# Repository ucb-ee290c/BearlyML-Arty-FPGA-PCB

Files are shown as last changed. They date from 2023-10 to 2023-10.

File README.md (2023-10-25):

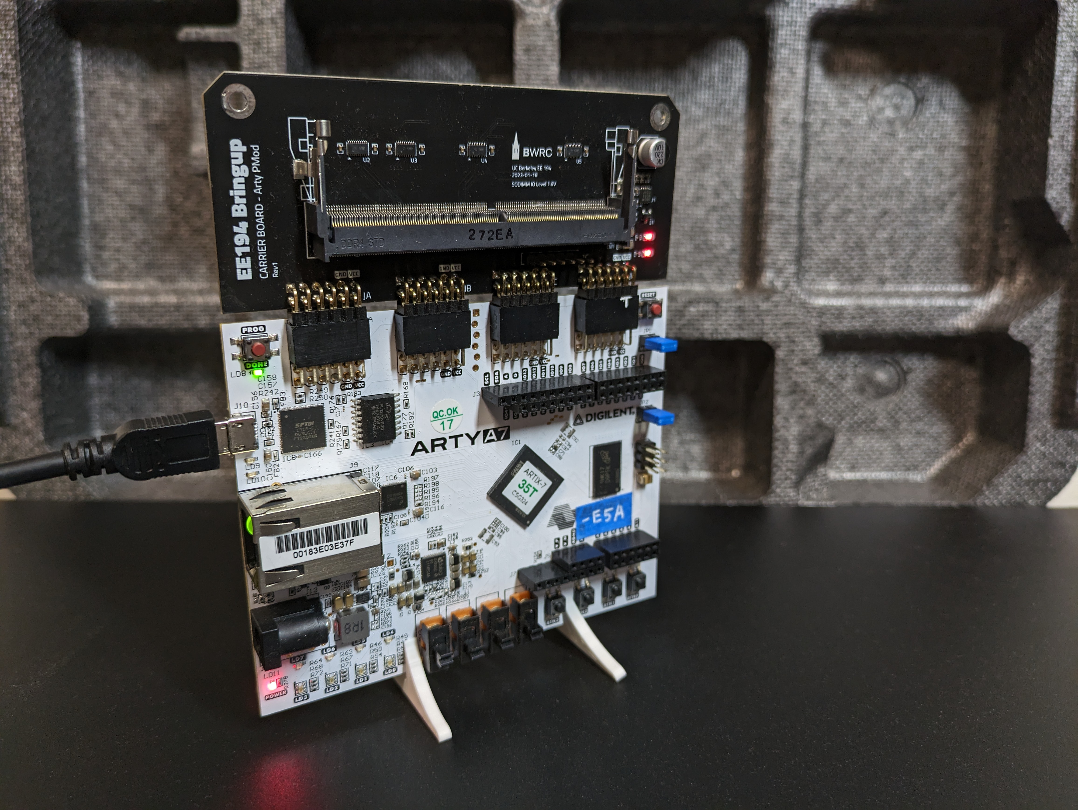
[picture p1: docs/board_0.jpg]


# BearlyML Carrier Arty PCB

This is an adapter board between BearlyML Module board and the Arty 35T / 100T FPGA.

## Functional Description

This board level-shifts between the BearlyML 1.8V signal and the Arty PMOD 3.3V signal using the [TXB0108DQSR](https://www.digikey.com/short/mvzwjjp7) level shifter. 

## Project Links

[BearlyML 2022 SoC Specification](https://docs.google.com/document/d/1Ldz2ZDB1uXTN-R59TmTNYh7_aXbSfiJJrKeP0uHo0qY/edit?usp=sharing)

[BearlyML 2022 Testing Note](https://docs.google.com/presentation/d/11BuBN2AjHtR5hc7lh9h7Z0UspvnxgiJxumvH6YZSuuI/edit?usp=sharing)

[PCB Project on GitHub](https://github.com/ucb-ee290c/BearlyML-Arty-FPGA-PCB)

[PCB Project on Altium 365](https://ucb-bar.365.altium.com/designs/37B6BC0A-9DBB-47C5-8C42-4A4CADA3A758#design)

[PCB Project on LCEDA](https://lceda.cn/editor#id=10e6a497bc3b4d0ba6b3146a791dbbba|b137350678f4478c931cfbcba87ce0c4|037f49d65316436faf2b81830ce06c8c|9a71b296f1f1483798a26e552317a1fd)

[PCB Project in BWRC-Boards](https://bwrcrepo.eecs.berkeley.edu/pcb/bearlyml-arty-carrier)

## Schematic

[View on Altium 365](https://ucb-bar.365.altium.com/designs/37B6BC0A-9DBB-47C5-8C42-4A4CADA3A758#design)

[Schematic PDF](schematic-pdf/Schematic_BearlyML%20Carrier%20Arty%20Board_2023-10-24.pdf)

## Fabrication Specifications

| Key | Value |
| ---- | --- |
| Build Time | 4-5 days |
| Layers | 4  |
| PCB Qty | 5 |
| PCB Thickness | 1.6 mm |
| Base Material | FR-4 |
| Material Type | FR4-Standard TG 135-140 |
| Dimension | 108 mm* 70 mm |
| Product Type | Industrial/Consumer electronics |
| Impedance Control | no |
| Silkscreen | White |
| PCB Color | Black |
| Surface Finish | LeadFree HASL |
| Via Covering | Tented |
| Outer Copper Weight | 1 oz |
| Inner Copper Weight | 0.5 oz |
| Castellated Holes | no |
| Min hole size/diameter | 0.2/0.45mm↑ |
| Flying Probe Test | Fully Test |
| Remove Order Number | Specify a location |
| Appearance Quality | IPC Class 2 Standard |
| Silkscreen Technology | Ink-jet/Screen Printing Silkscreen |

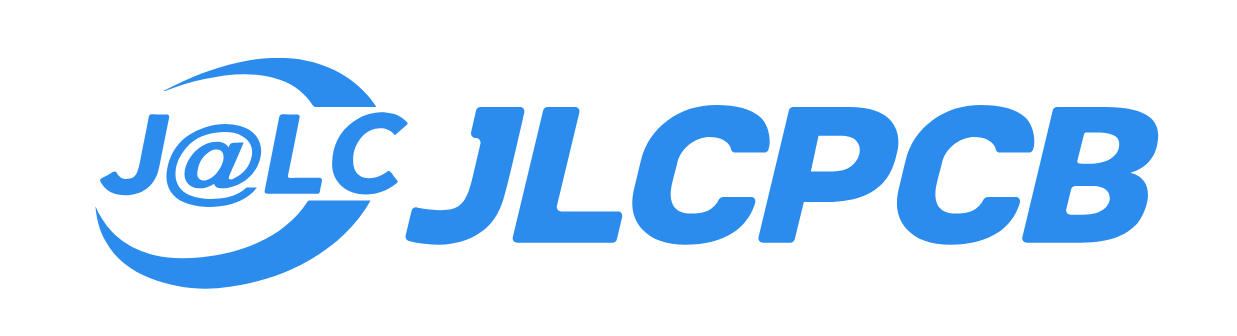
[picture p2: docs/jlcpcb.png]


Manufactured with [JLCPCB](https://jlcpcb.com/).

## Manufacture Cost

PCB: $11.78 each

Assembly: $20.80 each excluding BOM part cost

Total: $162.82 for 5 pcs

## 3D View

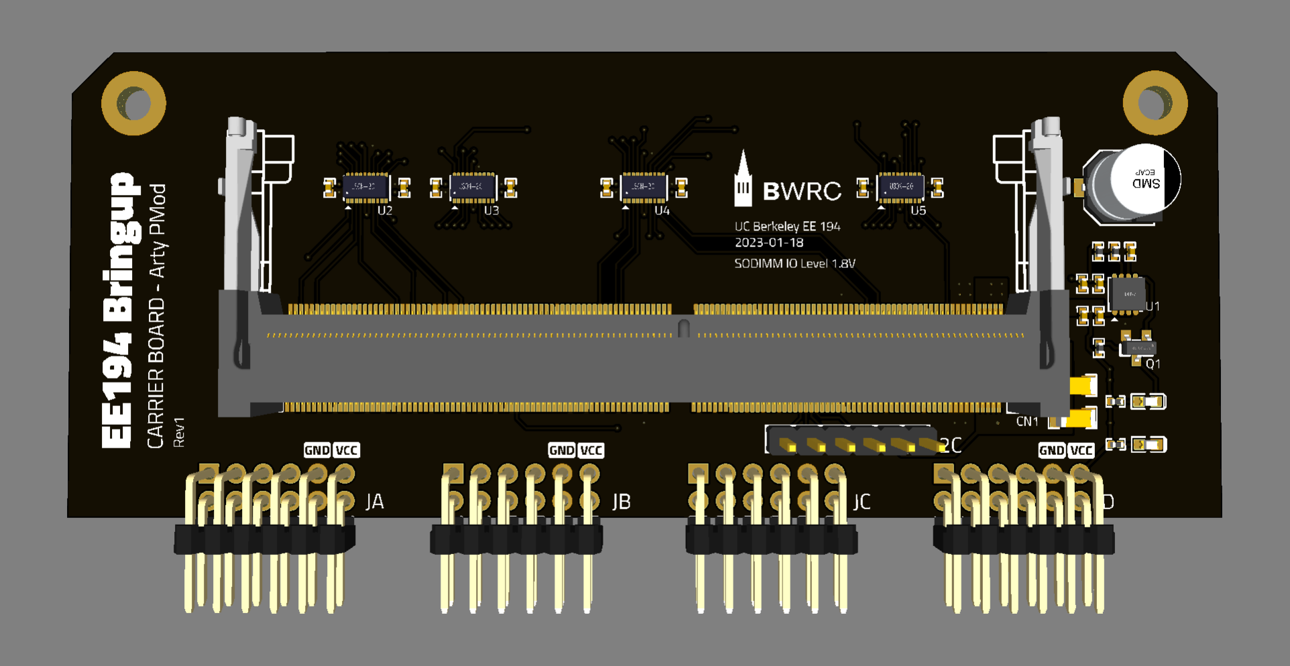
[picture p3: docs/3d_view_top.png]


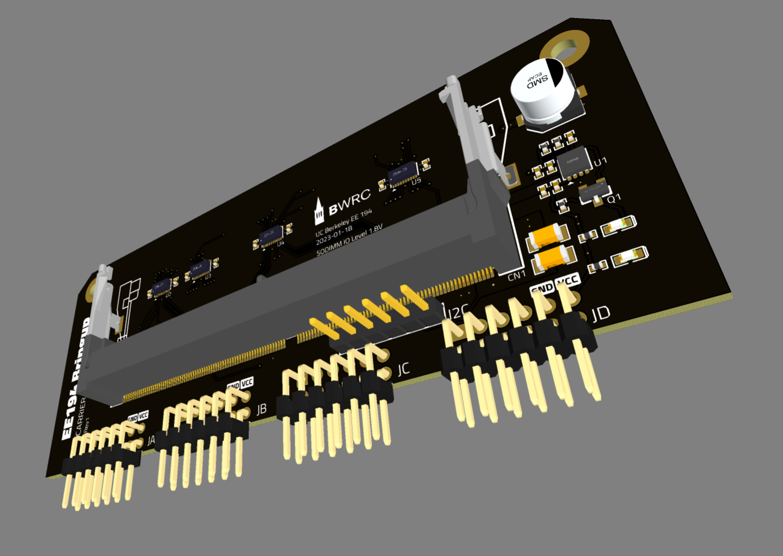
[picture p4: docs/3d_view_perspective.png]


## Real World View

#### Assembled with Arty 35T





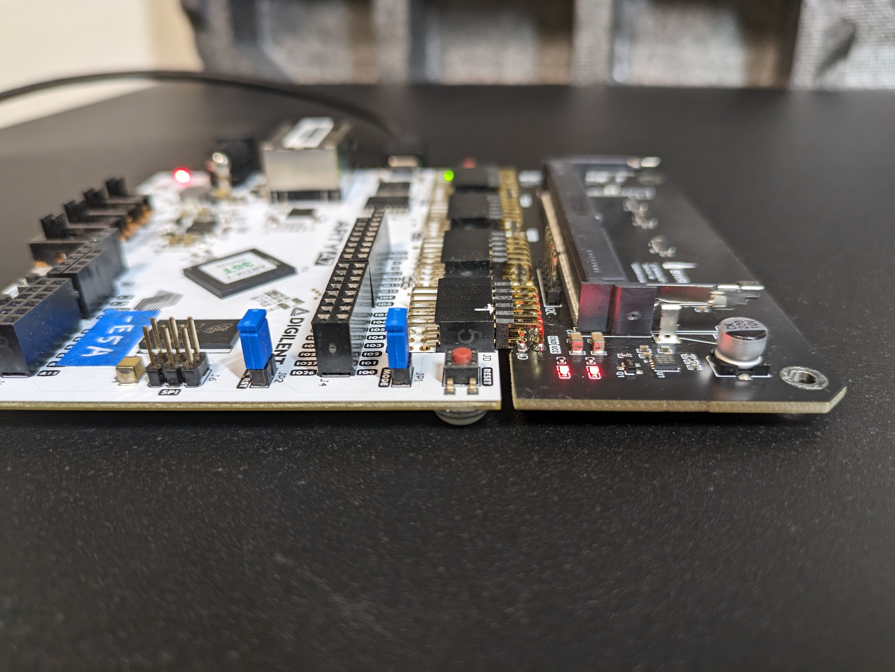
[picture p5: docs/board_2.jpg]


#### Assembled with Arty 35T and BearlyML Module board





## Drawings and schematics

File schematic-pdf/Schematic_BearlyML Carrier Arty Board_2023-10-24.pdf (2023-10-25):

## LDO

## Arty PMOD Connectors

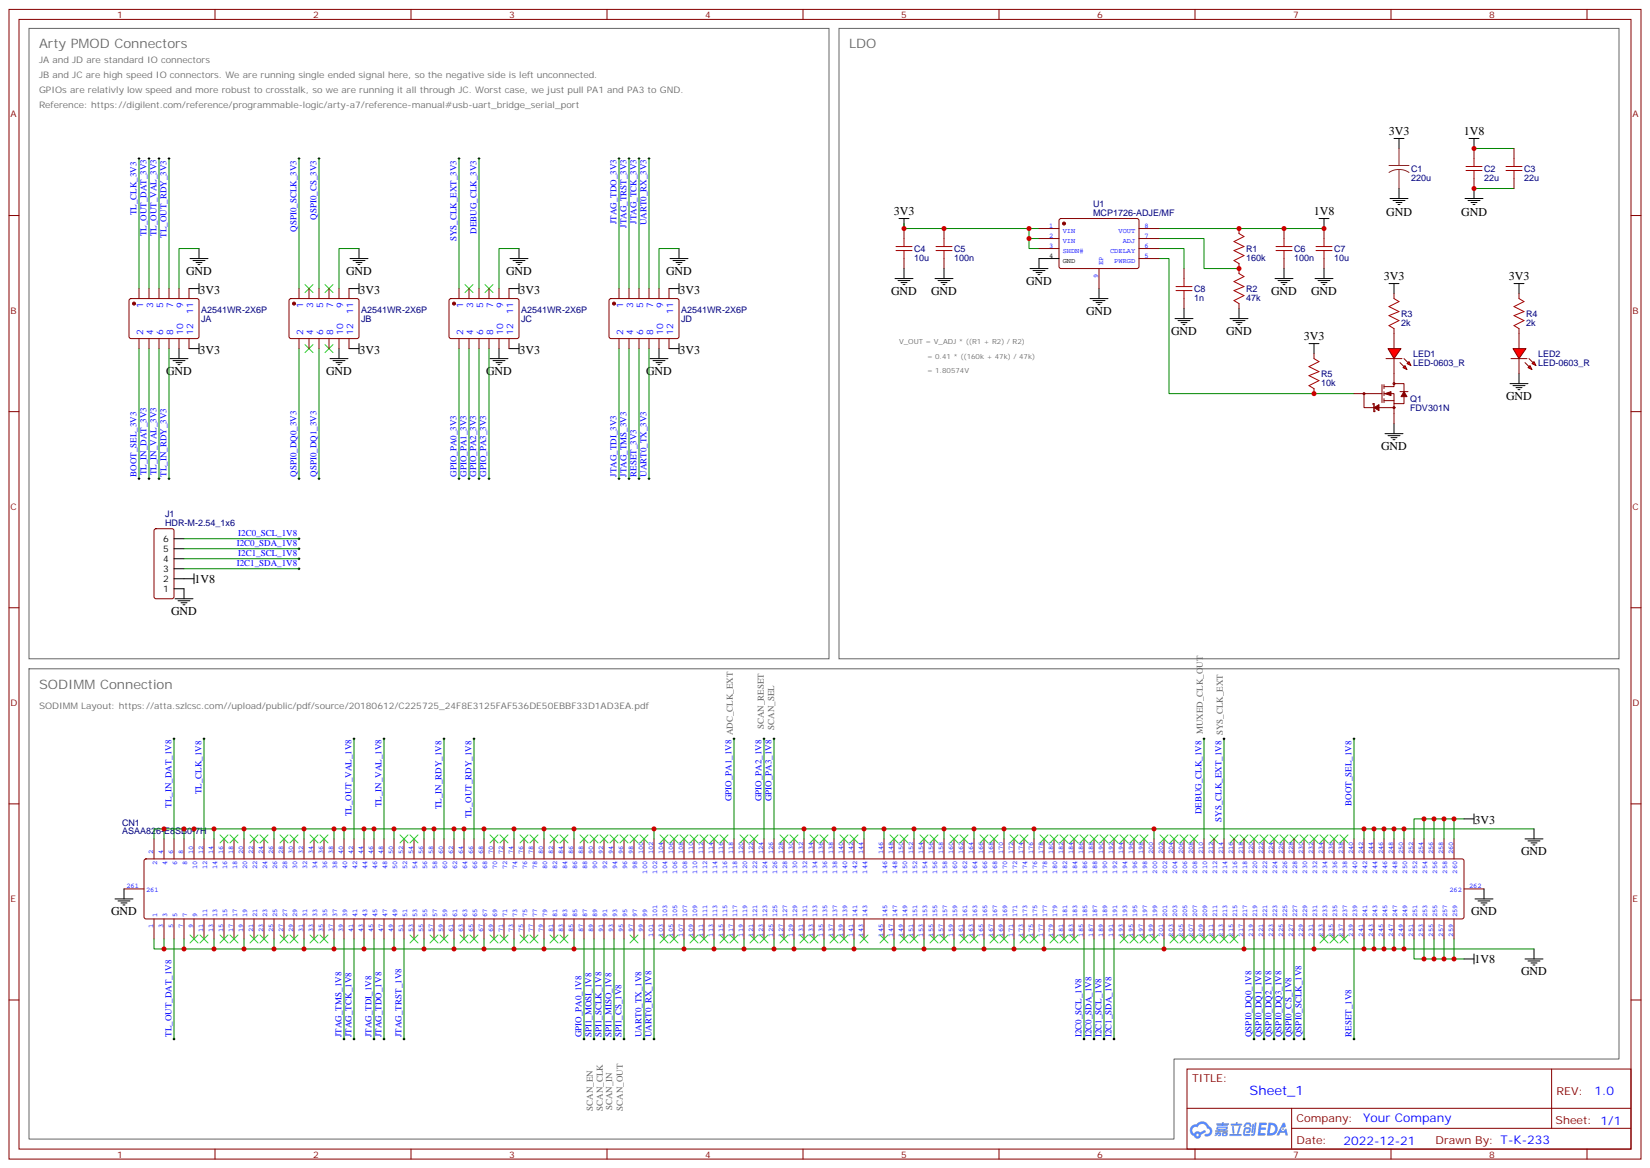
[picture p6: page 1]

JA and JD are standard IO connectors
JB and JC are high speed IO connectors. We are running single ended signal here, so the negative side is left unconnected.
GPIOs are relativly low speed and more robust to crosstalk, so we are running it all through JC. Worst case, we just pull PA1 and PA3 to GND.
Reference: https://digilent.com/reference/programmable-logic/arty-a7/reference-manual#usb-uart_bridge_serial_port

SODIMM Layout: https://atta.szlcsc.com//upload/public/pdf/source/20180612/C225725_24F8E3125FAF536DE50EBBF33D1AD3EA.pdf

## Level Shifts

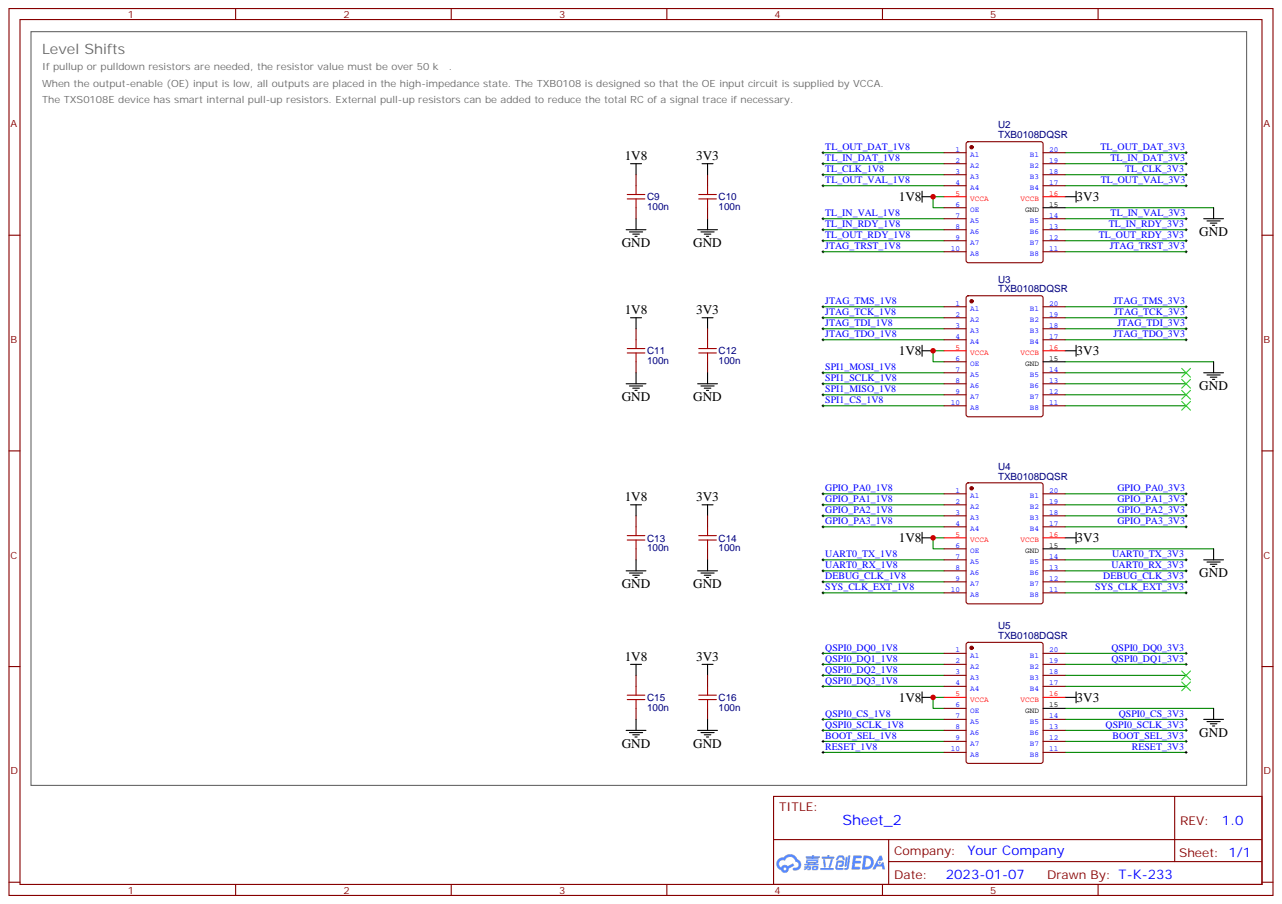
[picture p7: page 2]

If pullup or pulldown resistors are needed, the resistor value must be over 50 k .
When the output-enable (OE) input is low, all outputs are placed in the high-impedance state. The TXB0108 is designed so that the OE input circuit is supplied by VCCA.
The TXS0108E device has smart internal pull-up resistors. External pull-up resistors can be added to reduce the total RC of a signal trace if necessary.
